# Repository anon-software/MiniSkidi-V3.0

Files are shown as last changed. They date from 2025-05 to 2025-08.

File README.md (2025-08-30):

* Video at [youtube.com/watch?v=dDfVdGGrf1k](https://www.youtube.com/watch?v=dDfVdGGrf1k)
* Kits at [professorboots.com/products/rc-skidsteer-kit-v3-0](https://professorboots.com/products/rc-skidsteer-kit-v3-0?utm_medium=product_shelf)
* Tutorial at [professorboots.com/a/members](https://professorboots.com/a/members) (If self sourcing the parts you'll need to pay for a membershp to unlock that specific course)
* [3D Printed RC SkidSteer V3.0 printables](https://www.printables.com/de/model/721244-3d-printed-rc-skidsteer-v30)

The project depends on these libraries (the listed versions were tested):

* Async TCP by ESP32Async 3.4.7
* ESP Async WebServer by ESP32Async 3.8.0
* ESP32Servo by Kevin Harrington, John K. Bennett 3.0.9

Add the following Board Manager URLs:
* https://raw.githubusercontent.com/espressif/arduino-esp32/gh-pages/package_esp32_index.json
* https://raw.githubusercontent.com/ricardoquesada/esp32-arduino-lib-builder/master/bluepad32_files/package_esp32_bluepad32_index.json

The project depends on this boards packages (the listed versions were tested):

* esp32 by Espressif Systems 3.3.0
* esp32_bluepad32 by Ricardo Quesada 4.1.0

# Bluepad32 support for MiniSkidi V3.0

The game controller sketch is based on https://github.com/JohnFodero/MiniSkidi-V3.0. 

## Controls (for PS3)
 * Left X - Bucket Tilt
 * Left Y - Proportional Left Track Forward/Back
 * Right X - Arm Up/Down
 * Right Y - Proportional Right Track Foward Back
 * X - Toggle Lights

 Rumble activates when attempting to drive servos past their limit :)

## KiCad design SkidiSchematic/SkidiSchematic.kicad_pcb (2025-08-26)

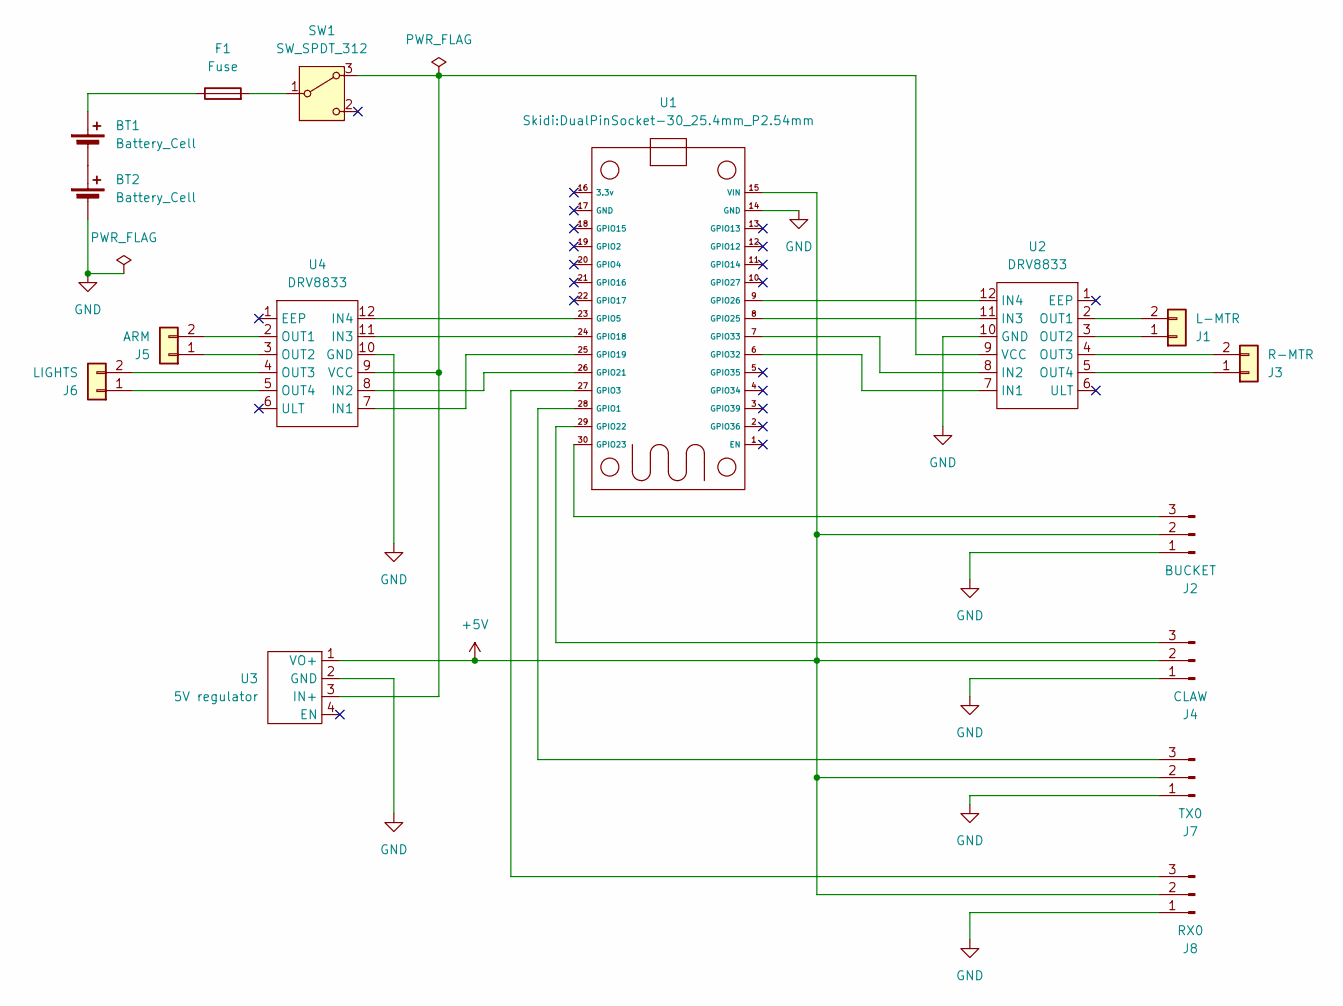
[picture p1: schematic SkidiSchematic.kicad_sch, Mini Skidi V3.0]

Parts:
BT1, BT2: Battery_Cell; CR123_holder
F1: Fuse; BLX-A
J1: L-MTR; JST_XH_B2B-XH-A_1x02_P2.50mm_Vertical
J2: BUCKET; PinHeader_1x03_P2.54mm_Vertical
J3: R-MTR; JST_XH_B2B-XH-A_1x02_P2.50mm_Vertical
J4: CLAW; PinHeader_1x03_P2.54mm_Vertical
J5: ARM; JST_XH_B2B-XH-A_1x02_P2.50mm_Vertical
J6: LIGHTS; JST_XH_B2B-XH-A_1x02_P2.50mm_Vertical
J7: TX0; PinHeader_1x03_P2.54mm_Vertical
J8: RX0; PinHeader_1x03_P2.54mm_Vertical
SW1: SW_SPDT_312; SW_Slide-03_SS-12D10_12.7x6.7x6.4_P4.7mm
U1: DualPinSocket-30_25.4mm_P2.54mm
U2, U4: DRV8833; DualPinSocket-12_15.24mm_P2.54mm
U3: 5V regulator; PinHeader_1x04_P2.54mm_Vertical

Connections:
+5V: J2.2, J4.2, J7.2, J8.2, U1.15 (VIN), U3.1 (VO+)
GND: BT2.2 (-), J2.1, J4.1, J7.1, J8.1, U1.14 (GND), U2.10 (GND), U3.2 (GND), U4.10 (GND)
unnamed: BT1.1 (+), F1.1
unnamed: BT1.2 (-), BT2.1 (+)
unnamed: J1.1, U2.3 (OUT2)
unnamed: J1.2, U2.2 (OUT1)
unnamed: J2.3, U1.30 (GPIO23)
unnamed: J3.1, U2.5 (OUT4)
unnamed: J3.2, U2.4 (OUT3)
unnamed: J4.3, U1.29 (GPIO22)
unnamed: J5.1, U4.3 (OUT2)
unnamed: J5.2, U4.2 (OUT1)
unnamed: J6.1, U4.5 (OUT4)
unnamed: J6.2, U4.4 (OUT3)
unnamed: J7.3, U1.28 (GPIO1)
unnamed: J8.3, U1.27 (GPIO3)
unnamed: SW1.3 (A), U2.9 (VCC), U3.3 (IN+), U4.9 (VCC)
unnamed: F1.2, SW1.1 (B)
unnamed: U1.23 (GPIO5), U4.12 (IN4)
unnamed: U1.24 (GPIO18), U4.11 (IN3)
unnamed: U1.25 (GPIO19), U4.7 (IN1)
unnamed: U1.26 (GPIO21), U4.8 (IN2)
unnamed: U1.8 (GPIO25), U2.11 (IN3)
unnamed: U1.9 (GPIO26), U2.12 (IN4)
unnamed: U1.6 (GPIO32), U2.7 (IN1)
unnamed: U1.7 (GPIO33), U2.8 (IN2)

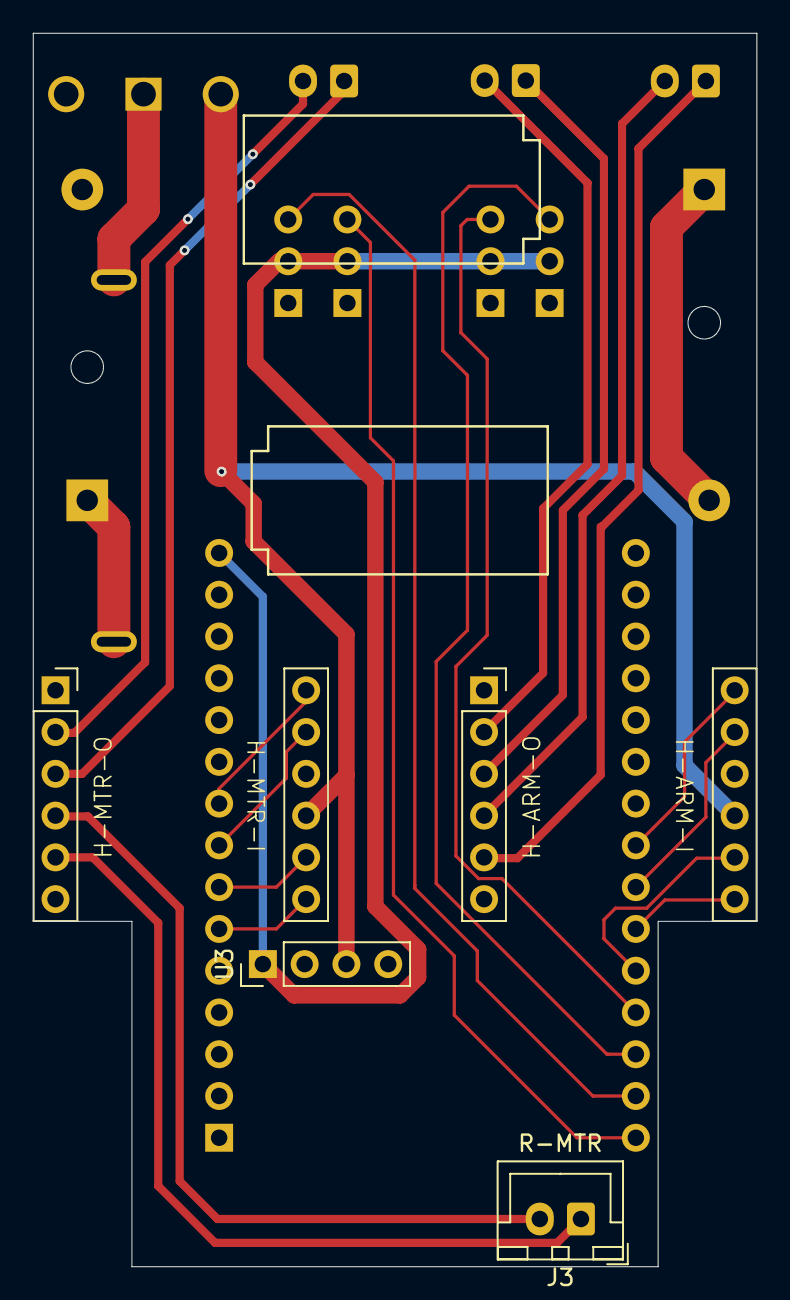
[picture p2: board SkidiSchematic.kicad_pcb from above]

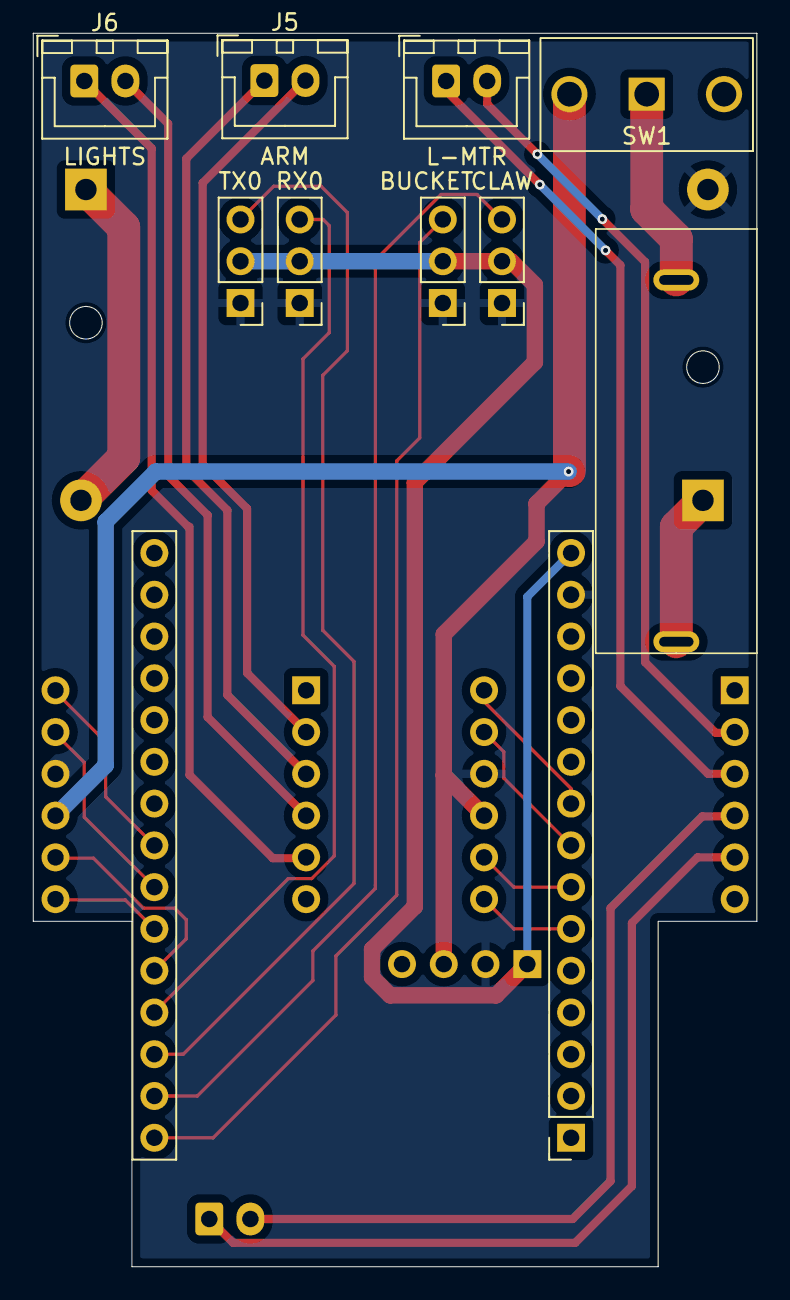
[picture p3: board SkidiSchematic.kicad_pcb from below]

Board: 2 copper layers, 44.0 x 75.0 mm, 16 parts (10 on the bottom side), 26 nets.

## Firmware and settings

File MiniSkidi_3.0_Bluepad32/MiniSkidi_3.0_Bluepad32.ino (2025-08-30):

/*
    Bluepad32 x MiniSkidi_3.0
*/
#include <Arduino.h>

#include <ESP32Servo.h> // by Kevin Harrington
#include <vector>
#include <Bluepad32.h>

// defines
#define bucketServoPin  23
#define auxServoPin 22
#define lightPin1 18
#define lightPin2 5

#define FORWARD 1
#define BACKWARD -1

#define DEAD_ZONE 20

#define MOTOR_PWM_FREQ 5000
#define MOTOR_PWM_RES 8

#define DEBOUNCE_MILLIS 300
#define RUBLE_MILLIS 1000

struct Measurement {
  int average = 0, countAverage = 0;
  int last = 0, countLast = 0;
  void reset() {
    average = 0; countAverage = 0;
    last = 0; countLast = 0;
  }
};
struct Calibration {
  Measurement
    axisX,
    axisY,
    axisRX,
    axisRY,
    brake,
    throttle;
  void reset() {
    axisX.reset();
    axisY.reset();
    axisRX.reset();
    axisRY.reset();
    brake.reset();
    throttle.reset();
  }
} calibration;

struct Debouncer {
  std::string name;
  unsigned long last = 0;
  unsigned long debounce;
  bool (Controller::*fptr)() const;
  bool press(ControllerPtr gamepad) {
    unsigned long now = millis();
    if (now - last > debounce) {
      if ((gamepad->*fptr)()) {
        last = now;
        if (name.length()>0)
          Serial.printf("button %s\n", name.c_str());
        return true;
      }
    }
    return false;
  }
  Debouncer(bool (Controller::*fptr)() const, long debounce = DEBOUNCE_MILLIS): fptr(fptr), debounce(debounce) {}
  Debouncer(const std::string &name, bool (Controller::*fptr)() const, long debounce = DEBOUNCE_MILLIS): Debouncer(fptr, debounce) {
    this->name = name;
  }
};

struct Throttle {
  unsigned long lastStart;
  unsigned long lastDuration;
  bool run(unsigned long duration) {
    unsigned long current = millis();
    if (current - lastStart >= lastDuration) {
      lastStart = current;
      lastDuration = duration;
      return true;
    }
    return false;
  }
};

Throttle rumbleThrottle;
void rumble(ControllerPtr gamepad, int duration) {
  if (rumbleThrottle.run(duration))
    gamepad->playDualRumble(0,         // delayedStartMs,
                            duration,  // durationMs,
                            0x80,      // weakMagnitude,
                            0xc0       // strongMagnitude
    );
}

struct ThrottledServo: Servo {
  Throttle servoThrottle;
  int servo_pos = 0;
  int lo, hi;
  int minThrottle, maxThrottle;
  int maxInput;
  int deadZone;
  void servoMove(ControllerPtr gamepad, int servoValue);
  ThrottledServo(int servo_pos, int lo, int hi, int minThrottle, int maxThrottle, int maxInput, int deadZone):
    servo_pos(servo_pos),
    lo(lo),
    hi(hi),
    minThrottle(minThrottle),
    maxThrottle(maxThrottle),
    maxInput(maxInput),
    deadZone(deadZone) {
  }
  void init(int pin) {
    int channel = attach(pin);
    Serial.printf("Attached %d %d\n", channel, servo_pos);
    write(servo_pos);
  }
};

ThrottledServo bucketServo(170, 10, 175, 8, 30, 511, 70); // Grabs PWM Channel 0
ThrottledServo auxServo(150, 90, 170, 12, 30, 1023, 70); // Grabs PWM Channel 1

bool light = false;
Debouncer x("rumble", &Controller::x);
Debouncer b("control", &Controller::b);
Debouncer a("light", &Controller::a);
Debouncer y("calibration", &Controller::y);

struct MOTOR_PINS
{
  int pinIN1;
  int pinIN2;
  int channel1;
  int channel2;
};

std::vector<MOTOR_PINS> motorPins =
{
  {25, 26, 2, 3},  //RIGHT_MOTOR Pins
  {33, 32, 4, 5},  //LEFT_MOTOR Pins
  {21, 19, 6, 7},  //ARM_MOTOR Pins
};

template <typename T> int sgn(T val) {
  return (T(0) < val) - (val < T(0));
}
void ThrottledServo::servoMove(ControllerPtr gamepad, int servoValue) {
  if (abs(servoValue) <= deadZone)
    return;
  servoValue = constrain(servoValue, -maxInput, maxInput);

  int x = map(abs(servoValue), 0, maxInput, maxThrottle, minThrottle);
  if (servoThrottle.run(x)) {
    int new_pos = servo_pos + sgn(servoValue);
    Serial.printf("Servo %d %d %d %d %lu\n", servoValue, x, servo_pos, new_pos, millis());
    if (new_pos > hi | new_pos < lo) {
      rumble(gamepad, RUBLE_MILLIS);
    }
    else if (new_pos != servo_pos) {
      servo_pos = new_pos;
      Serial.printf("servo_pos %d\n", servo_pos);
      write(servo_pos);
    }
  }
}
void bucketTilt(ControllerPtr gamepad, int bucketServoValue)
{
  bucketServo.servoMove(gamepad, bucketServoValue);
}
void auxControl(ControllerPtr gamepad, int auxServoValue)
{
  auxServo.servoMove(gamepad, auxServoValue);
}
void lightControl()
{
  if (!light)
  {
    digitalWrite(lightPin1, HIGH);
    digitalWrite(lightPin2, LOW);
    light = true;
  }
  else
  {
    digitalWrite(lightPin1, LOW);
    digitalWrite(lightPin2, LOW);
    light = false;
  }
}

void setUpPinModes()
{

  for (int i = 0; i < motorPins.size(); i++)
  {
    ledcSetup(motorPins[i].channel1, MOTOR_PWM_FREQ, MOTOR_PWM_RES);
    ledcAttachPin(motorPins[i].pinIN1, motorPins[i].channel1);
    ledcWrite(motorPins[i].channel1, 0);

    ledcSetup(motorPins[i].channel2, MOTOR_PWM_FREQ, MOTOR_PWM_RES);
    ledcAttachPin(motorPins[i].pinIN2, motorPins[i].channel2);
    ledcWrite(motorPins[i].channel2, 0);
  }

  bucketServo.init(bucketServoPin);
  auxServo.init(auxServoPin);

  pinMode(lightPin1, OUTPUT);
  pinMode(lightPin2, OUTPUT);
}

ControllerPtr myControllers[BP32_MAX_CONTROLLERS];

void setup() {
  Serial.begin(115200);
  while (!Serial) {
    // wait for serial port to connect.
  }

  setUpPinModes();
  String fv = BP32.firmwareVersion();
  Serial.print("Firmware version installed: ");
  Serial.println(fv);

  // To get the BD Address (MAC address) call:
  const uint8_t* addr = BP32.localBdAddress();
  Serial.print("BD Address: ");
  for (int i = 0; i < 6; i++) {
    Serial.print(addr[i], HEX);
    if (i < 5)
      Serial.print(":");
    else
      Serial.println();
  }

  BP32.setup(&onConnectedController, &onDisconnectedController);

  // "forgetBluetoothKeys()" should be called when the user performs
  // a "device factory reset", or similar.
  // Calling "forgetBluetoothKeys" in setup() just as an example.
  // Forgetting Bluetooth keys prevents "paired" gamepads to reconnect.
  // But might also fix some connection / re-connection issues.
  BP32.forgetBluetoothKeys();
}

void onConnectedController(ControllerPtr ctl) {
  bool foundEmptySlot = false;
  for (int i = 0; i < BP32_MAX_GAMEPADS; i++) {
    if (myControllers[i] == nullptr) {
      Serial.print("CALLBACK: Controller is connected, index=");
      Serial.println(i);
      myControllers[i] = ctl;
      foundEmptySlot = true;

      // Optional, once the gamepad is connected, request further info about the
      // gamepad.
      ControllerProperties properties = ctl->getProperties();
      char buf[80];
      sprintf(buf,
              "BTAddr: %02x:%02x:%02x:%02x:%02x:%02x, VID/PID: %04x:%04x, "
              "flags: 0x%02x",
              properties.btaddr[0], properties.btaddr[1], properties.btaddr[2],
              properties.btaddr[3], properties.btaddr[4], properties.btaddr[5],
              properties.vendor_id, properties.product_id, properties.flags);
      Serial.println(buf);
      break;
    }
  }
  if (!foundEmptySlot) {
    Serial.println(
        "CALLBACK: Controller connected, but could not found empty slot");
  }
}

void onDisconnectedController(ControllerPtr ctl) {
  bool foundGamepad = false;

  for (int i = 0; i < BP32_MAX_GAMEPADS; i++) {
    if (myControllers[i] == ctl) {
      Serial.print("CALLBACK: Controller is disconnected from index=");
      Serial.println(i);
      myControllers[i] = nullptr;
      foundGamepad = true;
      break;
    }
  }

  if (!foundGamepad) {
    Serial.println(
        "CALLBACK: Controller disconnected, but not found in myControllers");
  }
}

void stopAllMotors() {
  for (int i = 0; i < motorPins.size(); i++)
  {
    ledcWrite(motorPins[i].channel1, 0);
    ledcWrite(motorPins[i].channel2, 0);
  }
}

void calibrateOne(Measurement &m, int t) {
  if (m.last == t)
    m.countLast++;
  else
    m.countLast = 0;
  m.last = t;
  if (m.countLast >= 100) {
    long x = ((long)m.countLast * (long)m.last + (long)m.countAverage * (long)m.average) / ((long)m.countLast + (long)m.countAverage);
    m.average = x;
    m.countAverage += m.countLast;
    m.countLast = 0;
  }
}
void calibrateAll(ControllerPtr gamepad) {
  calibrateOne(calibration.axisX, gamepad->axisX());
  calibrateOne(calibration.axisY, gamepad->axisY());
  calibrateOne(calibration.axisRX, gamepad->axisRX());
  calibrateOne(calibration.axisRY, gamepad->axisRY());
  calibrateOne(calibration.brake, gamepad->brake());
  calibrateOne(calibration.throttle, gamepad->throttle());
  printf(
          "Calibration axis L: %4li-%4li, %4li-%4li, axis R: %4li-%4li, %4li-%4li, "
          "brake: %4ld-%4li, throttle: %4li-%4li\n",
          calibration.axisX.average,
          calibration.axisX.last,
          calibration.axisY.average,
          calibration.axisY.last,
          calibration.axisRX.average,
          calibration.axisRX.last,
          calibration.axisRY.average,
          calibration.axisRY.last,
          calibration.brake.average,
          calibration.brake.last,
          calibration.throttle.average,
          calibration.throttle.last
    );
}

/*
Traditionl control:
Left X - Bucket Tilt
Left Y - Proportional Left Track Forward/Back
Right X - Arm Up/Down
Right Y - Proportional Right Track Foward Back

Simplified control:
Left X - Move Forward/Backward
Left Y - Turn Left/Right
Right X - Arm Up/Down
Right Y - Bucket Tilt
*/
bool traditionalControl = true;

void propulsionControl(ControllerPtr gamepad, int &left_motor, int &right_motor) {
  if (traditionalControl) {
    left_motor = gamepad->axisY() - calibration.axisY.average;
    right_motor = gamepad->axisRY() - calibration.axisRY.average;
    if (abs(left_motor) <= DEAD_ZONE)
      left_motor = 0;
    if (abs(right_motor) <= DEAD_ZONE)
      right_motor = 0;
  }
  else {
    int speed = gamepad->axisY() - calibration.axisY.average; // Forward -512, Back 511
    if (abs(speed) <= DEAD_ZONE)
      speed = 0;
    int steer = gamepad->axisX() - calibration.axisX.average; // Left -512, Right 511
    if (abs(steer) <= DEAD_ZONE)
      steer = 0;

    double angle = atan2(speed, steer);
    double amplitude = sqrt(steer*steer + speed*speed);
    left_motor = (angle >= PI/2. ? 1 : (angle <= 0 && angle >= -PI/2.) ? -1 : angle > 0 ? cos(PI - angle * 2) : cos(angle * 2)) * amplitude;
    right_motor = ((angle >= 0 && angle <= PI/2.) ? 1 : (angle <= -PI/2. ? -1 : angle > PI/2. ? cos(PI - angle * 2) : cos(angle * 2))) * amplitude;

    left_motor = constrain(left_motor, -512, 512);
    right_motor = constrain(right_motor, -512, 512);
  }
}

int armControl(ControllerPtr gamepad) {
  int arm_motor = gamepad->axisRX() - calibration.axisRX.average;
  if (abs(arm_motor) <= DEAD_ZONE)
    arm_motor = 0;
  return arm_motor;
}

int bucketControl(ControllerPtr gamepad) {
  return traditionalControl? gamepad->axisX() - calibration.axisX.average: gamepad->axisRY() - calibration.axisRY.average;
}

void processGamepad(ControllerPtr gamepad) {
  static bool calibrationInProgress = false;
  if (calibrationInProgress) {
    calibrateAll(gamepad);
  }
  else {
    // Set motor speeds
    int left_motor;
    int right_motor;
    propulsionControl(gamepad, left_motor, right_motor);

    // update left motor speed
    int mapped_left = map(left_motor, -512, 512, -255, 255);
    if (mapped_left < 0) {
      ledcWrite(motorPins[1].channel1, -mapped_left);
      ledcWrite(motorPins[1].channel2, 0);
    } else {
      ledcWrite(motorPins[1].channel1, 0);
      ledcWrite(motorPins[1].channel2, mapped_left);
    }

    // update right motor speed
    int mapped_right = map(right_motor, -512, 512, -255, 255);
    if (mapped_right < 0) {
      ledcWrite(motorPins[0].channel1, -mapped_right);
      ledcWrite(motorPins[0].channel2, 0);
    } else {
      ledcWrite(motorPins[0].channel1, 0);
      ledcWrite(motorPins[0].channel2, mapped_right);
    }

    // set arm motor
    int arm_motor = armControl(gamepad);
    int mapped_arm = map(arm_motor, -512, 512, -255, 255);
    if (mapped_arm < 0) {
      ledcWrite(motorPins[2].channel1, 0);
      ledcWrite(motorPins[2].channel2, abs(mapped_arm));
    } else {
      ledcWrite(motorPins[2].channel1, mapped_arm);
      ledcWrite(motorPins[2].channel2, 0);
    }
    // set bucket servo
    int bucket_move = bucketControl(gamepad) - calibration.axisX.average;
    bucketTilt(gamepad, bucket_move);
    // set claw servo
    int claw_move = gamepad->throttle() - gamepad->brake();
    auxControl(gamepad, claw_move);
    // Set lights
    if (a.press(gamepad)) {
      lightControl();
    }

    // Rumble the controller
    if (x.press(gamepad)) {
      rumble(gamepad, RUBLE_MILLIS);
    }

    // Toggle traditional/simplified control
    if (b.press(gamepad)) {
      traditionalControl = !traditionalControl;
    }
/*
    Serial.printf(
            "idx=%d, dpad: 0x%02x, buttons: 0x%04x, "
            "axis L: %4li, %4li, axis R: %4li, %4li, "
            "brake: %4ld, throttle: %4li, misc: 0x%02x, "
            "gyro x:%6d y:%6d z:%6d, accel x:%6d y:%6d z:%6d, "
            "battery: %d",
            gamepad->index(),        // Gamepad Index
            gamepad->dpad(),         // DPAD
            gamepad->buttons(),      // bitmask of pressed buttons
            gamepad->axisX(),        // (-511 - 512) left X Axis
            gamepad->axisY(),        // (-511 - 512) left Y axis
            gamepad->axisRX(),       // (-511 - 512) right X axis
            gamepad->axisRY(),       // (-511 - 512) right Y axis
            gamepad->brake(),        // (0 - 1023): brake button
            gamepad->throttle(),     // (0 - 1023): throttle (AKA gas) button
            gamepad->miscButtons(),  // bitmak of pressed "misc" buttons
            gamepad->gyroX(),      // Gyro X
            gamepad->gyroY(),      // Gyro Y
            gamepad->gyroZ(),      // Gyro Z
            gamepad->accelX(),     // Accelerometer X
            gamepad->accelY(),     // Accelerometer Y
            gamepad->accelZ(),     // Accelerometer Z
            gamepad->battery()       // 0=Unknown, 1=empty, 255=full
    );
*/
  }
  if (y.press(gamepad)) {
    calibrationInProgress = !calibrationInProgress;
    if (calibrationInProgress)
      calibration.reset();
  }
}

void loop() {
  BP32.update();

  for (int i = 0; i < BP32_MAX_CONTROLLERS; i++) {
    ControllerPtr myController = myControllers[i];

    if (myController && myController->isConnected()) {
      if (myController->isGamepad())
        processGamepad(myController);
    } else {
      stopAllMotors();
    }
    vTaskDelay(1);
  }
}

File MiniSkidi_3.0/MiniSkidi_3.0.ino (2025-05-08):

/* ProfessorBoots
   John Cheroske 1/6/2024
   MiniSkidi 3.0

   Thank you to the following people for contributing to this sketch
   -TomVerr99 "Excellent Job organizing what was a very messy intial sketch"
   -CrabRC "I dont even know where to start, but thank you for making numerous improvemnts/suggestions
   across both mechanical designs and software."
   -Fortinbra "Always willing to provide the discord group with a good meme or two, as well as lend a helping hand
   in multiple ways."

  Some tidbits to check

  -Install the esp32 boards manager into the arduino IDE"
  Programming Electronics Academy has a good tutorial: https://youtu.be/py91SMg_TeY?si=m1OWPBPlK-QHJ2Xx"
  -Select "ESP32 Dev Module" under tools>Board>ESP32 Arduino before uploading sketch.
  -The following include statements with comments "by -----" are libraries that can be installed
  directly inside the arduino IDE under Sketch>Include Library>Manage Libraries
*/
#include <Arduino.h>

#include <ESP32Servo.h> // by Kevin Harrington
#include <ESPAsyncWebServer.h> // by ESP32Servo
#include <iostream>
#include <sstream>

#if defined(ESP32)
#include <AsyncTCP.h> // by ESP32Async
#include <WiFi.h>
#elif defined(ESP8266)
#include <ESPAsyncTCP.h> // by ESP32Async
#endif


// defines
#define bucketServoPin  23
#define auxServoPin 22
#define lightPin1 18
#define lightPin2 5
#define UP 1
#define DOWN 2
#define LEFT 3
#define RIGHT 4
#define ARMUP 5
#define ARMDOWN 6
#define STOP 0

#define RIGHT_MOTOR 1
#define LEFT_MOTOR 0
#define ARM_MOTOR 2

#define FORWARD 1
#define BACKWARD -1

// global constants

extern const char* htmlHomePage PROGMEM;
const char* ssid     = "ProfBoots MiniSkidi OG";

// global variables

Servo bucketServo;
Servo auxServo;

bool horizontalScreen;//When screen orientation is locked vertically this rotates the D-Pad controls so that forward would now be left.
bool removeArmMomentum = false;
bool light = false;

struct MOTOR_PINS
{
  int pinIN1;
  int pinIN2;
};

std::vector<MOTOR_PINS> motorPins =
{
  {25, 26},  //RIGHT_MOTOR Pins (IN1, IN2)
  {33, 32},  //LEFT_MOTOR  Pins
  {21, 19}, //ARM_MOTOR pins
};

AsyncWebServer server(80);
AsyncWebSocket wsCarInput("/CarInput");


void rotateMotor(int motorNumber, int motorDirection)
{
  if (motorDirection == FORWARD)
  {
    digitalWrite(motorPins[motorNumber].pinIN1, HIGH);
    digitalWrite(motorPins[motorNumber].pinIN2, LOW);
  }
  else if (motorDirection == BACKWARD)
  {
    digitalWrite(motorPins[motorNumber].pinIN1, LOW);
    digitalWrite(motorPins[motorNumber].pinIN2, HIGH);
  }
  else
  {
    if (removeArmMomentum)
    {
      digitalWrite(motorPins[ARM_MOTOR].pinIN1, HIGH);
      digitalWrite(motorPins[ARM_MOTOR].pinIN2, LOW);
      delay(10);
      digitalWrite(motorPins[motorNumber].pinIN1, LOW);
      digitalWrite(motorPins[motorNumber].pinIN2, LOW);
      delay(5);
      digitalWrite(motorPins[ARM_MOTOR].pinIN1, HIGH);
      digitalWrite(motorPins[ARM_MOTOR].pinIN2, LOW);
      delay(10);
      removeArmMomentum = false;
    }
    digitalWrite(motorPins[motorNumber].pinIN1, LOW);
    digitalWrite(motorPins[motorNumber].pinIN2, LOW);
  }
}

void moveCar(int inputValue)
{
  Serial.printf("Got value as %d\n", inputValue);
  if (!(horizontalScreen))
  {
    switch (inputValue)
    {

      case UP:
        rotateMotor(RIGHT_MOTOR, FORWARD);
        rotateMotor(LEFT_MOTOR, FORWARD);
        break;

      case DOWN:
        rotateMotor(RIGHT_MOTOR, BACKWARD);
        rotateMotor(LEFT_MOTOR, BACKWARD);
        break;

      case LEFT:
        rotateMotor(RIGHT_MOTOR, BACKWARD);
        rotateMotor(LEFT_MOTOR, FORWARD);
        break;

      case RIGHT:
        rotateMotor(RIGHT_MOTOR, FORWARD);
        rotateMotor(LEFT_MOTOR, BACKWARD);
        break;

      case STOP:
        rotateMotor(ARM_MOTOR, STOP);
        rotateMotor(RIGHT_MOTOR, STOP);
        rotateMotor(LEFT_MOTOR, STOP);
        break;

      case ARMUP:
        rotateMotor(ARM_MOTOR, FORWARD);
        break;

      case ARMDOWN:
        rotateMotor(ARM_MOTOR, BACKWARD);
        removeArmMomentum = true;
        break;

      default:
        rotateMotor(ARM_MOTOR, STOP);
        rotateMotor(RIGHT_MOTOR, STOP);
        rotateMotor(LEFT_MOTOR, STOP);
        break;
    }
  } else {
    switch (inputValue)
    {
      case UP:
        rotateMotor(RIGHT_MOTOR, BACKWARD);
        rotateMotor(LEFT_MOTOR, FORWARD);
        break;

      case DOWN:
        rotateMotor(RIGHT_MOTOR, FORWARD);
        rotateMotor(LEFT_MOTOR, BACKWARD);
        break;

      case LEFT:
        rotateMotor(RIGHT_MOTOR, BACKWARD);
        rotateMotor(LEFT_MOTOR, BACKWARD);
        break;

      case RIGHT:
        rotateMotor(RIGHT_MOTOR, FORWARD);
        rotateMotor(LEFT_MOTOR, FORWARD);
        break;

      case STOP:
        rotateMotor(ARM_MOTOR, STOP);
        rotateMotor(RIGHT_MOTOR, STOP);
        rotateMotor(LEFT_MOTOR, STOP);
        break;

      case ARMUP:
        rotateMotor(ARM_MOTOR, FORWARD);
        break;

      case ARMDOWN:
        rotateMotor(ARM_MOTOR, BACKWARD);
        removeArmMomentum = true;
        break;

      default:
        rotateMotor(ARM_MOTOR, STOP);
        rotateMotor(RIGHT_MOTOR, STOP);
        rotateMotor(LEFT_MOTOR, STOP);
        break;
    }
  }
}

void bucketTilt(int bucketServoValue)
{
  bucketServo.write(bucketServoValue);
}
void auxControl(int auxServoValue)
{
  auxServo.write(auxServoValue);
}
void lightControl()
{
  if (!light)
  {
    digitalWrite(lightPin1, HIGH);
    digitalWrite(lightPin2, LOW);
    light = true;
    Serial.println("Made it to lights");
  }
  else
  {
    digitalWrite(lightPin1, LOW);
    digitalWrite(lightPin2, LOW);
    light = false;
  }
}

void handleRoot(AsyncWebServerRequest *request)
{
  request->send_P(200, "text/html", htmlHomePage);
}

void handleNotFound(AsyncWebServerRequest *request)
{
  request->send(404, "text/plain", "File Not Found");
}
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

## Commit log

2025-05-08 Unresolved external linking the web server
    Switching to another library fixes the problem.
    [MiniSkidi_3.0.ino]
2025-06-24 KiCad schematic
    The schematic includes UART connectors for debugging. See
    https://randomnerdtutorials.com/esp32-uart-communication-serial-arduino/
    [SkidiSchematic.kicad_pcb, SkidiSchematic.kicad_sch]
2025-06-26 Add game controller support by John Fodero
    The servo pins are reversed and angle limits adjusted from the original
    implementation.
    [MiniSkidi_3.0_Bluepad32.ino]
2025-06-26 Smoother bucket and claw operation
    Dead zone value of 10 seems too low for XBOX controller where an idle
    joystick may outpuvalues as high as 60. We can get away with smaller
    values for the motors.
    The neutral joysticks' position still gives non-zero redouts. The dead
    zone value is there to neutralise them. However, it would be better if
    we can compensate them to some degree. The calibration mode can now be
    activated and the user should jiggle the joysticks a bit and then let
    them stay in the netral position for a few seconds. However, this feature
    is of a dubious benefit because the values read from joysticks seem to
    drift at rest.
    [MiniSkidi_3.0_Bluepad32.ino]
2025-06-26 Simplified control
    An alternate gamepad control can be toggled by pressing on the B button.
    The left joystick alone controls both motors in this mode which is arguably
    easier.
2025-08-20 Flip simplified steering when reversing
    [MiniSkidi_3.0_Bluepad32.ino]
2025-08-26 Move switch to the other PCB side
    [SkidiSchematic.kicad_pcb]
2025-08-30 No PWM without logging
    The loop delay that yields the CPU to the PWM maintenance was outside
    the loop and thus not having any effect. Without logging through the
    serial output which itself presumably allows the maintenance thread to
    kick in, the motors practically do not move.
    Interestingly, it somewhat works if channel 8 and above are used. It
    seems that ESP32Servo library designates channels 0-7 as low speed
    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
